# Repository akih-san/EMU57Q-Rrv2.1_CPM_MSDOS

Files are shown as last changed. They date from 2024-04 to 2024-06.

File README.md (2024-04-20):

# EMU57Q-8088/V20<br>
<br>
PIC18F57Q43を使った8088/用のSBCを作成し、CPM-86とMD-DOS2.11を移植し公開しています。<br>
SBCをRev2.1にバージョンアップしました。<br>
8088/V20が4.9MHz、または8MHzで動作します。<br>

EMU57Q-8088/V20 Rev2.1ボード
P 1

Rev2.1では、新たにI2Cをサポートしています。<br>

SBCとI2Cモジュール
P 2

また、新規ファームウェアでは、起動時ＯＳを選択出来るようにしました。<br>
ファイルは、CPM-86用のディレクトリファイルと、MS-DOS用のディレクトリ<br>
ファイルが用意されています。<br>
両方のディレクトリファイルをSDカードにコピーすると、どちらのOSを<br>
起動時するのかをパワーオン／リセット時に聞いてきます。<br>
単一のディレクトリファイルをコピーした場合には、コピーしたOSが起動します。<br>
<br>

CP/M-86起動画面
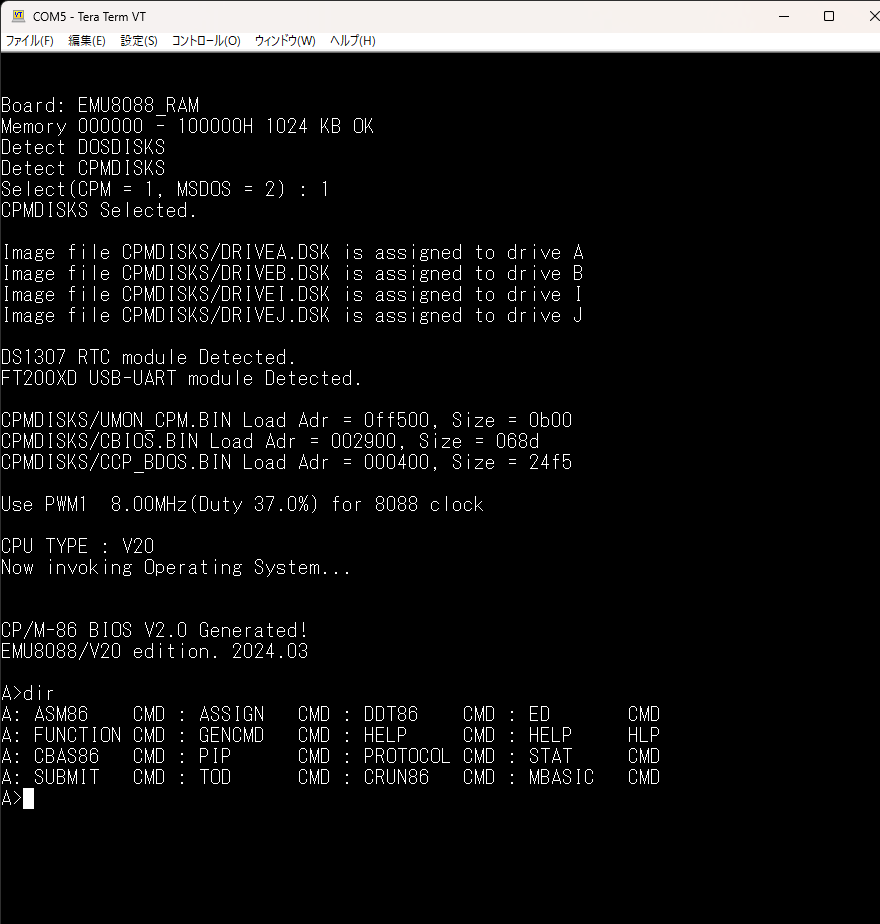
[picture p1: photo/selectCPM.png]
P 3


MS-DOS起動画面
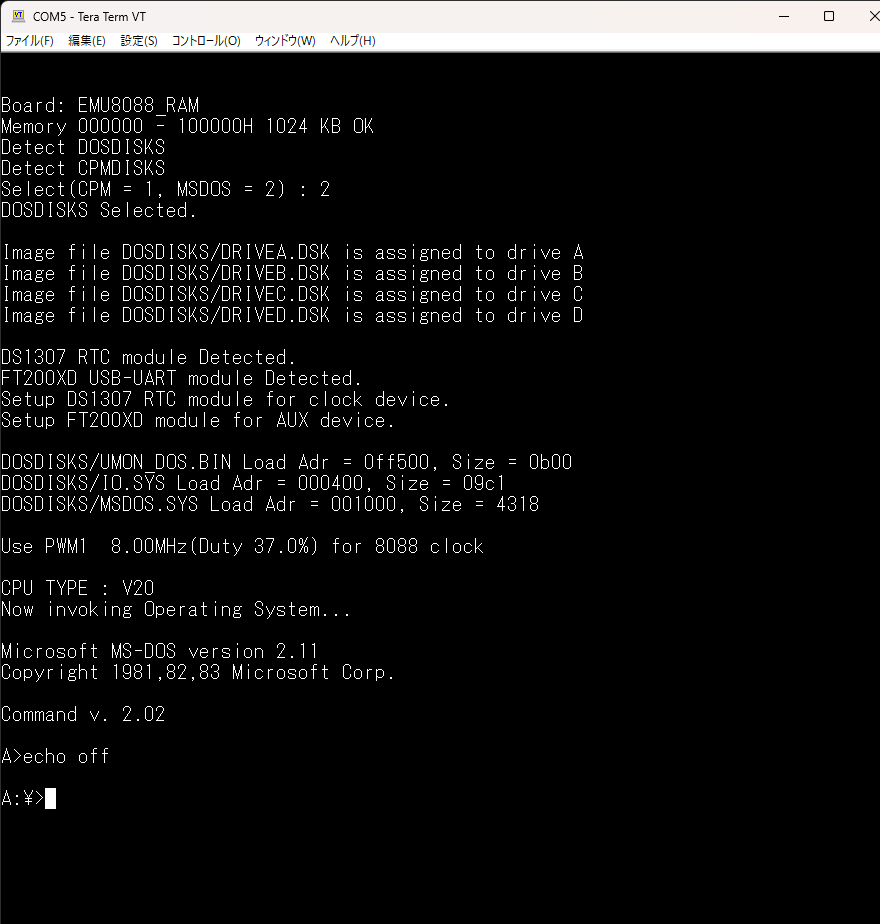
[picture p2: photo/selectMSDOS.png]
P 4


# I2Cのサポート<br>
MS-DOSのクロックデバイスをサポートするためには、リアルタイムクロック<br>
（RTC）が必要です。<br>
PIC18F57Q43にはRTC機能はありません。<br>
（タイマーを使って疑似的に1秒を作り出すことはできます。）<br>
商業用にI2C機能を使ったRTCモジュールが販売されています。<br>
PIC18F57Q43にはI2C機能があるので、これを使えばRTC機能を持たせることが可能となります。<br>
<br>
そういった理由から、I2Cをサポートすることにしました。<br>
また、I2Cを使えば、商業用に販売されている色々なデバイスを動かす<br>
ことが出来ます。<br>
（当然対応するプログラムを作成する必要がありますが・・・）<br>
RTCモジュールとしてサポートしているのは、DS1307を使用したモジュール<br>
となります。また、I2C経由でUSB-UARTに接続するモジュール（FT200-XD)の<br>
サポートも実装してあります。<br>
<br>
I2Cが使えるのは、MS-DOSのみとなっています。CPM-86では扱っていません。<br>
<br>
I2Cのサポートについては、@etoolsLab369さんのページが非常に参考になりました。<br>
感謝いたします。<br>
<br>
（18F27Q43 2台を使ってHost-Client通信）<br>
https://qiita.com/etoolsLab369/items/65befd8fe1cccd3afc33<br>
<br>
<br>
＜DS1307を使ったRTCモジュール＞
P 5
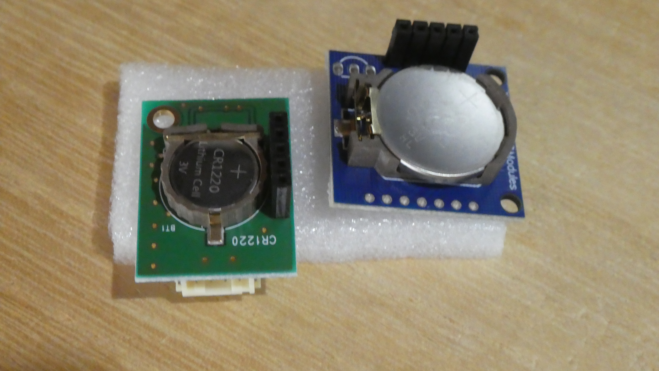
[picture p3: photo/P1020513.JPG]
P 6


AE-DS1307：　秋月電子通商で入手できます。<br>
https://akizukidenshi.com/catalog/g/g115488/<br>
<br>
Tiny RTC modules：　amazon、その他有名webストアで入手できます。<br>
説明書も何もありませんが、amazonに図面入りのレビューがありました。<br>
<br>
<br>
＜FT200XDを使ったUSB-UART接続モジュール＞
P 7

MFT200XD：　マルツのwebストアで入手できます。amazonからでも入手できます。<br>
https://www.marutsu.co.jp/pc/i/243038/<br>
<br>
CJMCU-200：　amazon、その他有名webストアで入手できます。<br>
説明書も何もありませんでしたが、問題なく使えました。<br>
<br>
<br>
# ファームウェア
@hanyazouさんが作成したZ80で動作しているCP/M-80のFWをベースに、<br>
EMU8088_57Q用のFWとして動作するように修正を加えました。<br>
今回は、CPM-86とMS-DOSを、SDカード上にバイナリファイルとして扱っています。<br>
<br>
(CPM-86)<br>
--CPMDISKSディレクトリ<br>
　　CBIOS.BIN　　　　BIOSバイナリファイル<br>
　　CCP_BDOS.BIN　　　CCP, BDOSバイナリファイル<br>
　　UMON_CPM.BIN　　　UNIMONのバイナリファイル<br>
　　DRIVEA.DSK　　　　Aドライブのディスクイメージ<br>
　　DRIVEB.DSK　　　　Bドライブのディスクイメージ<br>
　　DRIVEI.DSK　　　　Iドライブのディスクイメージ<br>
　　DRIVEJ.DSK　　　　Jドライブのディスクイメージ<br>
<br>
(MS-DOS)<br>
--DOSDISKSディレクトリ<br>
　　IO.SYS　　　　　　IOデバイスドライバのバイナリファイル<br>
　　MSDOS.SYS　　　　MS-DOS本体のバイナリファイル<br>
　　UMON_DOS.BIN　　　UNIMONのバイナリファイル<br>
　　DRIVEA.DSK　　　　Aドライブのディスクイメージ<br>
　　DRIVEB.DSK　　　　Bドライブのディスクイメージ<br>
　　DRIVEC.DSK　　　　Cドライブのディスクイメージ<br>
　　DRIVED.DSK　　　　Dドライブのディスクイメージ<br>
<br>
MS-DOS、CPM-86については、以下を参照してください。<br>
<br>
https://github.com/akih-san/EMU8088_57Q_V2_CPM86<br>
https://github.com/akih-san/EMU8088_MSDOS211<br>
<br>
<br>
＜＠hanyazouさんのソース＞<br>
https://github.com/hanyazou/SuperMEZ80/tree/mez80ram-cpm<br>
<br>
＜@electrelicさんのユニバーサルモニタ(UNIMON)＞<br>
https://electrelic.com/electrelic/node/1317<br>
<br>
<br>
# 参考
・EMUZ80<br>
EUMZ80はZ80CPUとPIC18F47Q43のDIP40ピンIC2つで構成されるシンプルな<br>
コンピュータです。<br>
<br>
＜電脳伝説 - EMUZ80が完成＞  <br>
https://vintagechips.wordpress.com/2022/03/05/emuz80_reference  <br>
＜EMUZ80専用プリント基板 - オレンジピコショップ＞  <br>
https://store.shopping.yahoo.co.jp/orangepicoshop/pico-a-051.html<br>
<br>
・SuperMEZ80<br>
SuperMEZ80は、EMUZ80にSRAMを追加し、Z80をノーウェイトで動かすことができるメザニンボードです<br>
<br>
SuperMEZ80<br>
https://github.com/satoshiokue/SuperMEZ80<br>
<br>

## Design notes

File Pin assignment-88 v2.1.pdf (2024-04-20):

8088_RAM

EMUZ80-8088 PIC18F57Q43 | Bit
7 | 6 | 5 | 4 | 3 | 2 | 1 | 0
RA | RXD (UART3) | (UART3) TXD | HOLDA | /A19 (not A19) | A19 | A18 | A17 | A16
U3（74LS373の出力）
RB | AD7 - AD0（DATA BUSとして使用）
（DAA　Bと共用）→ | MISO (SPI1) | SPI_CK (SPI1) | MOSI (SPI1)
RC | CLK （PWM1S1P1_OUT) | NMI / GPIO （I2C設定用） | ALE | SDA(I2C1) / RXD(UART1) | SCL(I2C1) / TXD(UART1) | /RD | /WR | IO/M#
RD | A7 - A0 U2（74LS373）の出力
RE | | | | | | SPI_SS (SPI1) | HOLD | RESET
RF | A15 - A8

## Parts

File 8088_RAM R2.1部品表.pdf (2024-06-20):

8088_RAM R2.1部品表
No. | 部品番号 | 数 | 値、品番 | 名称
1 | C1 | 1 | 47μF 10V以上 | 電解コンデンサー
2 | C2, C3, C4, C5, C6, C7, C8, C9 | 8 | 0.1μF | 積層セラミックコンデンサー
3 | D1, D3, D4 | 3 | ３ｍｍLED | 発光ダイオード
4 | D2 | 1 | 1N4148 | 小信号ダイオード
5 | J1, J2, J3, J4 | 4 | 02x06 | PIC18F47Q43用のソケット（または、ピンヘッダ）
6 | J5 | 1 | MJ-179PH | 2.1mm標準DCジャック(4A) 基板取付用
7 | J6 | 1 | 1x06 | PICプログラム用、2.54mmピッチピンヘッダ
8 | J7 | 1 | 1x06 | μSDカード（SPI)用、2.54mmピッチピンヘッダ
9 | J8 | 1 | 1x06 | UART用、2.54mmピッチピンヘッダ
10 | J9 | 1 | 02x24 | 拡張用2.54mmピッチピンヘッダ
11 | J10 | 1 | 1x03 | TEST信号LOW、HIGH切替用2.54mmピッチピンヘッダ
12 | J11 | 1 | 1x05 | I2C接続用2.54mmピッチピンヘッダ
13 | J12 | 1 | 1x05 | I2C接続用2.54mmピッチピンヘッダ
14 | JP1 | 1 | Jumper(Open) | USB電源接続用ジャンパー2.54mm、２パッド
15 | JP2 | 2 | RSCL | I2Cプルアップ抵抗用ジャンパー2.54mm、２パッド
16 | JP3 | 1 | RSDA | I2Cプルアップ抵抗用ジャンパー2.54mm、２パッド
17 | JP4 | 2 | I2CIO | I2CIOオプションピン接続用ジャンパー2.54mm、２パッド
18 | R1 | 1 | 2.2KΩ 1/4W | カーボン抵抗(炭素皮膜抵抗)
19 | R2, R3, R4, R6, R8, R9 | 6 | 10KΩ 1/4W | カーボン抵抗(炭素皮膜抵抗)
20 | R5, R7 | 2 | 1.5KΩ 1/4W | カーボン抵抗(炭素皮膜抵抗)
21 | RN1 | 1 | 6素子 10kΩ | 集合抵抗 6素子
22 | RN2, RN3, RN4 | 3 | 8素子 10kΩ | 集合抵抗 8素子
23 | S1 | 1 | SS-12D00G3 | スライドスイッチ 1回路2接点 基板用
24 | SW1 | 1 | DTS-63-N-V | タクトスイッチ（リセット用）
25 | U1 | 1 | CPU 8088 / V20 | 8088または、V20（DIP40)
26 | U2, U3 | 2 | 74LS373 | 8ビットラッチ（DIP20)
27 | U4, U5 | 2 | AS6C4008-55PCN | 512kw×8bit SRAM（DIP32)
28 | U6 | 1 | 74HC125 | スリーステートバッファ（4回路、DIP14）
29 | PIC18F57Q43 | 1 | AE-QFP48PR5-DIP | PIC18F57Q43実装基板

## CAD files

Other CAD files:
i86src/msdos/emu88io.OBJ
i86src/msdos/SYSIMES.OBJ
i86src/msdos/SYSINIT.OBJ

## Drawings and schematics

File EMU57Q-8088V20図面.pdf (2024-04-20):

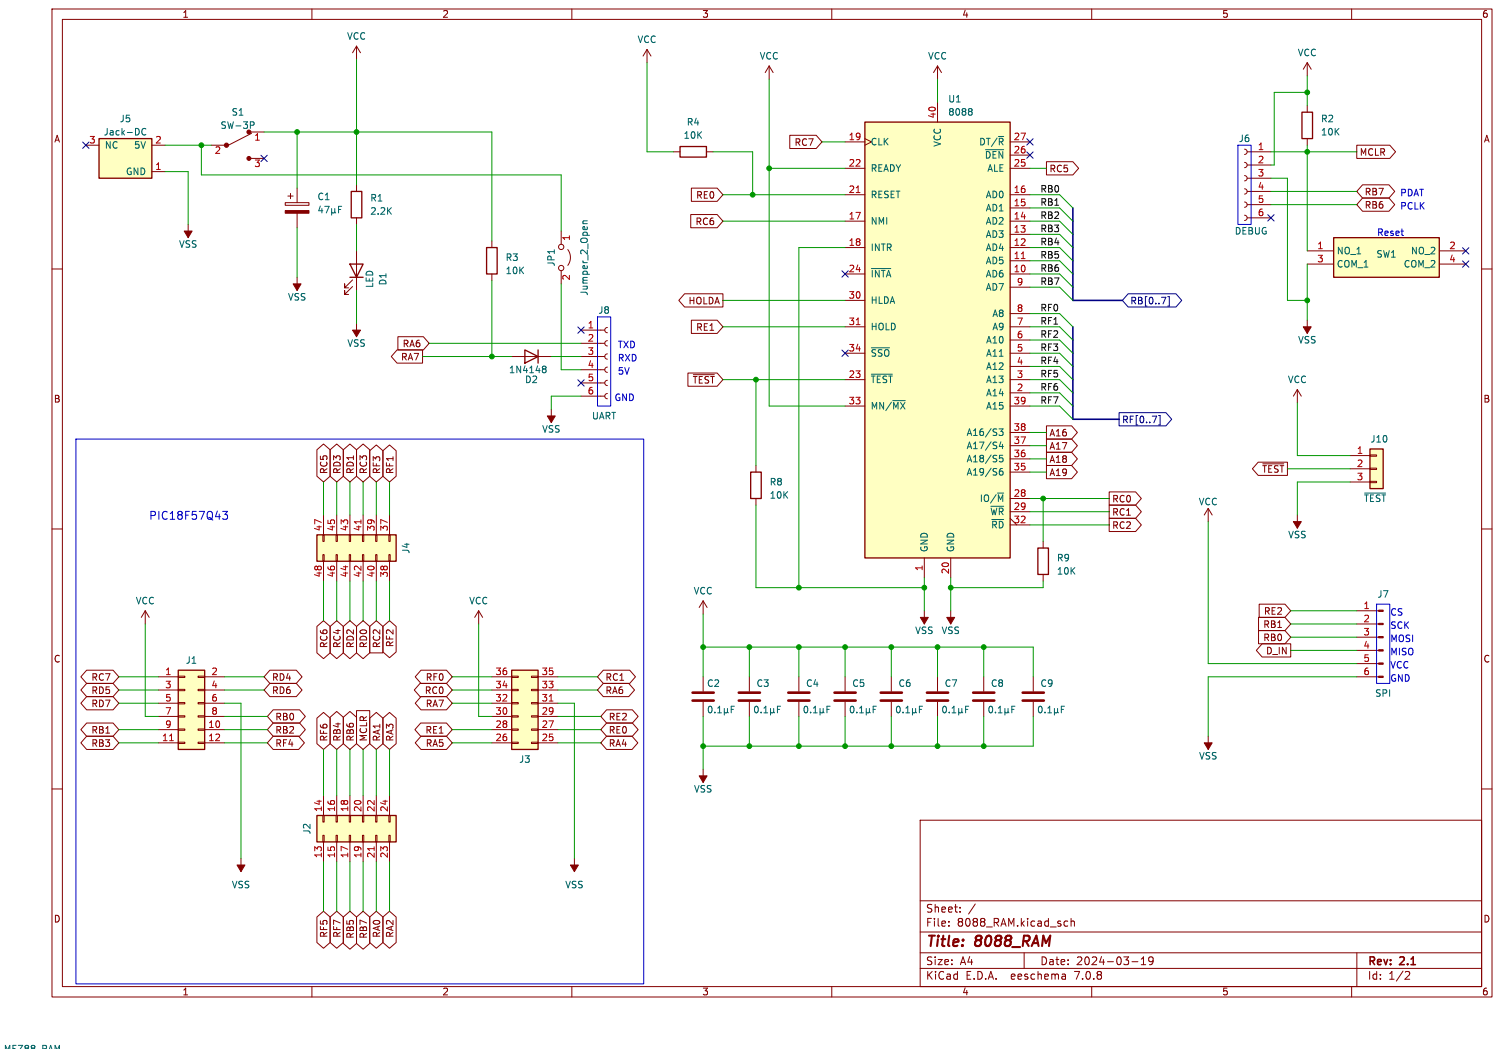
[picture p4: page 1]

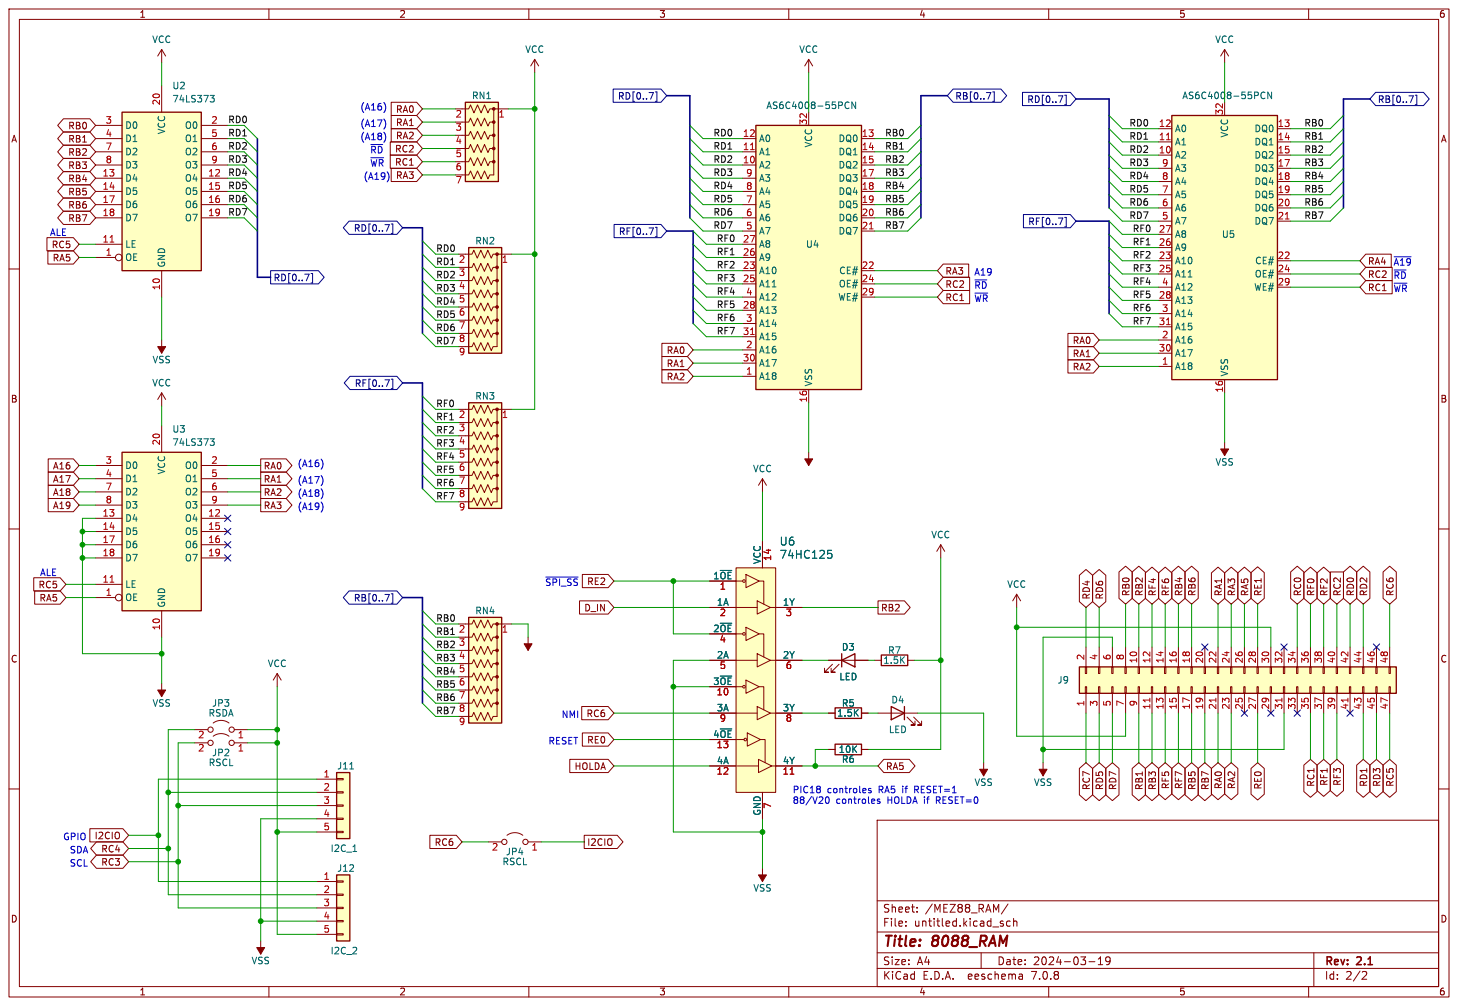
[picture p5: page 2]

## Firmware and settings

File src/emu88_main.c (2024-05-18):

/*
 * CP/M-86 and MS-DOS for EMU57Q-8088/V20_RAM
 * This firmware is only for PICF57Q43.
 * This firmware can run CPM-86 or MS-DOS on CPU i8088/V20.
 *
 * Based on main.c by Tetsuya Suzuki 
 * and emuz80_z80ram.c by Satoshi Okue
 * PIC18F47Q43/PIC18F47Q83/PIC18F47Q84 ROM image uploader
 * and UART emulation firmware.
 * This single source file contains all code.
 *
 * Base source code of this firmware is maked by
 * @hanyazou (https://twitter.com/hanyazou) *
 *
 *  Target: EMU57Q-8088/V20_RAM 1MB Rev2.1
 *  Written by Akihito Honda (Aki.h @akih_san)
 *  https://twitter.com/akih_san
 *  https://github.com/akih-san
 *
 *  Date. 2024.4.20
 */

#define INCLUDE_PIC_PRAGMA
#include "../src/emu88.h"
#include <stdio.h>
#include <stdlib.h>
#include <string.h>
#include "../drivers/utils.h"

static FATFS fs;
static DIR fsdir;
static FILINFO fileinfo;
static FIL files[NUM_FILES];
static FIL rom_fl;

uint8_t tmp_buf[2][TMP_BUF_SIZE];
#define BUF_SIZE TMP_BUF_SIZE * 2

static int os_flg;
debug_t debug = {
    0,  // disk
    0,  // disk_read
    0,  // disk_write
    0,  // disk_verbose
    0,  // disk_mask
};

static char *cpmdir	= "CPMDISKS";
static char *msdosdir	= "DOSDISKS";

static int disk_init(void);
static int chk_os(void);
static void setup_cpm(void);
static void setup_msdos(void);
static int open_dskimg(void);
static int load_program(const TCHAR *buf, uint32_t load_adr, uint16_t *load_size);

static char *board_name = "EMU8088_RAM";

// main routine
void main(void)
{
	sys_init();
	devio_init();

	printf("Board: %s\n\r", board_name);

    mem_init();
    if (disk_init() < 0) while (1);

	// Check OS
	os_flg = chk_os();		//1: CPM,  2:MSDOS, -1:error
	printf("\n\r");

	// open disk drive
	if ( open_dskimg() < 0 ) {
        printf("No boot disk.\n\r");
		while(1);
	}
	printf("\n\r");

	switch( os_flg ) {
		case CPM:
			setup_cpm();
			break;
		case MSDOS:
			setup_msdos();
			break;
		default:
			printf("No OS directory.\n\r");
			while (1);
	}

	printf("\n\r");

	//
    // Start i8088
    //
    printf("Use PWM1  %.2fMHz(Duty %.1f%%) for 8088 clock\n\r", 
    			1/((PWM1PR+1)*P64)*1000, (double)(PWM1S1P1*100/(PWM1PR+1)));
    printf("\n\r");
	
    start_i88();
	board_event_loop();
}

static void setup_msdos(void) {

	const TCHAR	buf[30];
	int flg;
	uint16_t size, sec_size, ld_adr;

	// set dos operation 
	bus_master_operation = dos_bus_master_operation;

	dosio_init();
	setup_clk_aux();
	printf("\n\r");

	sec_size = dos_sec_size();
	sprintf((char *)buf, "%s/UMON_DOS.BIN", fileinfo.fname);
	flg = load_program(buf, UNIMON_OFF, &size);
	if (!flg) {
		sprintf((char *)buf, "%s/IO.SYS", fileinfo.fname);
		flg = load_program(buf, IOSYS_OFF, &size);
		if (!flg) {
			ld_adr = (((size+sec_size) / sec_size)+1)*sec_size+IOSYS_OFF;
			sprintf((char *)buf, "%s/MSDOS.SYS", fileinfo.fname);
			flg = load_program(buf, (uint32_t)ld_adr, &size);
		}
	}
	if ( flg ) {
		printf("Program File Load Error.\r\n");
		while(1);
	}
}


static void setup_cpm(void) {
	
	const TCHAR	buf[30];
	int flg;
	uint16_t size;

	// set cpm operation
	bus_master_operation = cpm_bus_master_operation;

	cpmio_init();
	setup_I2C();
	if (!chk_i2cdev()) setup_uart1();
	printf("\n\r");

	sprintf((char *)buf, "%s/UMON_CPM.BIN", fileinfo.fname);
	flg = load_program(buf, UNIMON_OFF, &size);
	if (!flg) {
		sprintf((char *)buf, "%s/CBIOS.BIN", fileinfo.fname);
		flg = load_program(buf, BIOS_OFF, &size);
		if (!flg) {
			sprintf((char *)buf, "%s/CCP_BDOS.BIN", fileinfo.fname);
			flg = load_program(buf, CCP_OFF, &size);
		}
	}
	if ( flg ) {
		printf("Program File Load Error.\r\n");
		while(1);
	}
}

//
// load program from SD card
//
static int load_program(const TCHAR *buf, uint32_t load_adr, uint16_t *load_size) {
	
	FRESULT		fr;
	void		*rdbuf;
	UINT		btr, br;
	uint16_t	cnt;
	uint32_t	adr;

	rdbuf = (void *)&tmp_buf[0][0];		// program load work area(512byte)
	
	fr = f_open(&rom_fl, buf, FA_READ);
	if ( fr != FR_OK ) return((int)fr);

	adr = load_adr;
	cnt = *load_size = (uint16_t)f_size(&rom_fl);	// get file size
	btr = BUF_SIZE;									// default 512byte
	while( cnt ) {
		fr = f_read(&rom_fl, rdbuf, btr, &br);
		if (fr == FR_OK) {
			write_sram(adr, (uint8_t *)rdbuf, (unsigned int)br);
			adr += (uint32_t)br;
			cnt -= (uint16_t)br;
			if (btr > (UINT)cnt) btr = (UINT)cnt;
		}
		else break;
	}
	if (fr == FR_OK) {
		printf("%s Load Adr = %06lx, Size = %04x\r\n", (char *)buf, load_adr, *load_size);
	}
	f_close(&rom_fl);
	return((int)fr);
}

//
// mount SD card
//
static int disk_init(void)
{
    if (f_mount(&fs, "0://", 1) != FR_OK) {
        printf("Failed to mount SD Card.\n\r");
        return -2;
    }

    return 0;
}

//
// check OS and select OS
//
static int chk_os(void)
{
    int selection;
    uint8_t c;

    //
    // Select disk image folder
    //
    if (f_opendir(&fsdir, "/")  != FR_OK) {
        printf("Failed to open SD Card..\n\r");
        return -1;
    }

	selection = 0;
	f_rewinddir(&fsdir);
	while (f_readdir(&fsdir, &fileinfo) == FR_OK && fileinfo.fname[0] != 0) {
		if (strcmp(fileinfo.fname, cpmdir) == 0) {
			selection |= CPM;
			printf("Detect %s\n\r", fileinfo.fname);
		}
		if (strcmp(fileinfo.fname, msdosdir) == 0) {
			selection |= MSDOS;
			printf("Detect %s\n\r", fileinfo.fname);
		}
	}
	switch( selection) {
		case 0:			// directory not found
			return(-1);

		case CPM:
		case MSDOS:
			break;

		default:
			// remain CPM+MSDOS:
           	selection = CPM;
    	    printf("Select(CPM = 1, MSDOS = 2) : ");
    	    while (1) {
            	c = (uint8_t)getch();  // Wait for input char
    	    	if ( c == '1' || c == '2' ) {
    	    		putch((char)c);
	            	selection = c - '0';
    	    	}
   	    		if ( c == 0x0d || c == 0x0a ) break;
    	    }
   	    	printf("\n\r");
	}
	if ( selection == CPM) strcpy(fileinfo.fname, cpmdir);
	else strcpy(fileinfo.fname, msdosdir);
	printf("%s Selected.\n\r", fileinfo.fname);
	f_closedir(&fsdir);
	
	return(selection);
}

	
//
// Open disk images
//
static int open_dskimg(void) {
	
	int num_files;
    uint16_t drv;
	
	for (drv = num_files = 0; drv < NUM_DRIVES && num_files < NUM_FILES; drv++) {
        char drive_letter = (char)('A' + drv);
        char * const buf = (char *)tmp_buf[0];
        sprintf(buf, "%s/DRIVE%c.DSK", fileinfo.fname, drive_letter);
        if (f_open(&files[num_files], buf, FA_READ|FA_WRITE) == FR_OK) {

        	printf("Image file %s/DRIVE%c.DSK is assigned to drive %c\n\r",
                   fileinfo.fname, drive_letter, drive_letter);
        	if (os_flg == CPM) {
	        	cpm_drives[drv].filep = &files[num_files];
				if (cpm_drives[0].filep == NULL) return -4;
        	}
        	else {
        		dos_drives[drv].filep = &files[num_files];
				if (dos_drives[0].filep == NULL) return -4;
        	}
        	num_files++;
        }
    }
    return 0;
}

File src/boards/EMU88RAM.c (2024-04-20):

/*
 *  This source is for PIC18F57Q43 UART, I2C, SPI and TIMER0
 *
 * Base source code is maked by @hanyazou
 *  https://twitter.com/hanyazou
 *
 * Redesigned by Akihito Honda(Aki.h @akih_san)
 *  https://twitter.com/akih_san
 *  https://github.com/akih-san
 *
 *  Target: PIC18F57QXX
 *  Date. 2024.4.20
*/

#define BOARD_DEPENDENT_SOURCE

#include "../../src/emu88.h"
#include <stdio.h>
#include "../../drivers/SDCard.h"
#include "../../drivers/picregister.h"

#define SPI_PREFIX      SPI_SD
#define SPI_HW_INST     SPI1
#include "../../drivers/SPI.h"

#define I88_DATA        B
#define I88_ADDR_H      F
#define I88_ADDR_L      D

#define I88_A16		A0
#define I88_A17		A1
#define I88_A18		A2
#define I88_A19		A3

#define I88_IOM		C0
#define I88_ALE		C5

#define I88_RESET	E0
#define I88_HOLD	E1		// BUS request
#define I88_HOLDA	A5

// /WR
#define I88_WR		C1
// /RD
#define I88_RD		C2

// CLK
#define I88_CLK		C7
#define I88_NMI		C6

#define SPI_SS		E2
#define SPI_SD_POCI	B2

#define SPI_SD_PICO     B0
#define SPI_SD_CLK      B1
#define SPI_SD_SS       SPI_SS

#define URT1_RXD		C4
#define URT1_TXD		C3


#define CMD_REQ CLC3OUT

#include "emu88_common.c"

static void reset_ioreq(void);
void (*bus_master_operation)(void);

void sys_init()
{
    emu88_common_sys_init();

	// NMI definition
	WPU(I88_NMI) = 0;     // disable week pull up
	PPS(I88_NMI) = 0;     // set as latch port
	LAT(I88_NMI) = 0;     // NMI=0
	TRIS(I88_NMI) = 0;    // Set as output

	// HOLD output pin
    LAT(I88_HOLD) = 1;
    TRIS(I88_HOLD) = 0;          // Set as output
	
	// IO/#M
	WPU(I88_IOM) = 1;     // I88_IOM Week pull up
	LAT(I88_IOM) = 0;     // memory /CE active
	TRIS(I88_IOM) = 0;    // Set as onput

	// ALE
	WPU(I88_ALE) = 0;     // disable week pull up
    TRIS(I88_ALE) = 1;    // Set as input

	// /WR output pin
	WPU(I88_WR) = 1;		// /WR Week pull up
    LAT(I88_WR) = 1;		// disactive
    TRIS(I88_WR) = 0;		// Set as output
    PPS(I88_WR) = 0x00;	//reset:output PPS is LATCH

	// /RD output pin
	WPU(I88_RD) = 1;		// /WR Week pull up
    LAT(I88_RD) = 1;		// disactive
    TRIS(I88_RD) = 0;		// Set as output
    PPS(I88_RD) = 0x00;	//reset:output PPS is LATCH

	// SPI_SS
	WPU(SPI_SS) = 1;     // SPI_SS Week pull up
	LAT(SPI_SS) = 1;     // set SPI disable
	TRIS(SPI_SS) = 0;    // Set as onput

	LAT(I88_CLK) = 1;	// 8088_CLK = 1
    TRIS(I88_CLK) = 0;	// set as output pin
	
	//RA4 : setup /A19
	WPUA4 = 1;			// Week pull up
	TRISA4 = 0;			// Set as output
	RA4PPS = 0x01;		// CLC1OUT ( not A19 ) -> RA4

// Setup CLC
//
	//========== CLC pin assign ===========
    CLCIN4PPS = 0x15;			// assign RC5(ALE)
    CLCIN5PPS = 0x10;			// assign RC0(IO/M#)
	CLCIN0PPS = 0x03;			// assign RA3(A19)

	//========== CLC1 : make not A19  ==========
	CLCSELECT = 0;		// CLC1 select

	CLCnSEL0 = 0;		// CLCIN0PPS : RA3(A19)
	CLCnSEL1 = 127;		// NC
	CLCnSEL2 = 127;		// NC
	CLCnSEL3 = 127;		// NC

    CLCnGLS0 = 0x01;	// invert A19 -> log1
    CLCnGLS1 = 0x00;	// not gated
    CLCnGLS2 = 0x00;	// not gated
    CLCnGLS3 = 0x00;	// not gated

    CLCnPOL = 0x0e;		// POL=0, (G4POL,G3POL,G2POL)=1, G1POL=1
    CLCnCON = 0x82;		// 4-Input AND , no interrupt occurs

	
	//========== CLC3 : IOREQ ==========
	// reset DFF with software(reset_ioreq();)

	CLCSELECT = 2;		// CLC3 select

	CLCnSEL0 = 4;		// CLCIN4PPS : RC5(ALE)
    CLCnSEL1 = 5;		// CLCIN5PPS : RC0(IO/M#)
	CLCnSEL2 = 0x35;	// CLC3OUT
	CLCnSEL3 = 127;		// NC

    CLCnGLS0 = 0x02;	// ALE -> (log1) DFF(CK)
	CLCnGLS1 = 0x08;	// IO/#M - > (log2) OR gate
    CLCnGLS2 = 0x00;	// not gated
    CLCnGLS3 = 0x20;	// CLC3OUT -> (log4) OR gate

    CLCnPOL = 0x00;		// POL=0
    CLCnCON = 0x85;		// 2-Input DFF with R , no interrupt occurs

	// reset CLC3
	reset_ioreq();

	// SPI data and clock pins slew at maximum rate

	SLRCON(SPI_SD_PICO) = 0;
	SLRCON(SPI_SD_CLK) = 0;
	SLRCON(SPI_SD_POCI) = 0;

/*********** CLOCK TIMING ************************
 I88_CLK TIMING REQUIREMENTS(MUST)
 CLK Low Time  : minimum 118ns
 CLK High Time : minimum 69ns
*************************************************/

/**************** PWM1 ********************
// 8088 TIMING REQUIREMENTS(MUST)
// CLK Low Time  : minimum 118ns
// CLK High Time : minimum 69ns
// CLK duty 33%

// P64 = 1/64MHz = 15.625ns
// P5  = 1/5MHz  = 200ns = P64 * 12.8
// P8  = 1/8MHz  = 125nz = P64 * 8
//
// --- 4.92MHz ---
// Set PWM Left Aligned mode
// PR = 12
// P1 = 5 : P64*5 = 78.125ns
// P2 = 8 : P64*8 = 125ns
// MODE = 0
//     high period time: 78.125ns
//     low period time: 125ns
//     78.125 + 125ns = 203.125ns f = 4923076.9230769230769230769230769 Hz
//     duty = 38.4%
// --- 8MHz ---
// Set PWM Left Aligned mode
// PR = 7
// P1 = 3 : P64*3 = 46.875ns
// P2 = 5 : P64*5 = 78.125ns
// MODE = 0
//     high period time: 46.875ns
//     low period time: 78.125ns
//     46.875ns + 78.125 = 125ns f = 8 Hz
//     duty = 37.5%
******************************************/

	PWM1CLK = 0x02;		// Fsoc
	PWM1GIE = 0x00;		// interrupt disable
#ifdef CLK8M
//8MHz
	PWM1PR = 0x0007;	// 8 periods ( 0 - 7 )
	PWM1S1P1 = 0x0003;	// P1 = 3
	PWM1S1P2 = 0x0005;	// P2 = 5
#else
//5MHz
	PWM1PR = 0x000C;	// 13 periods ( 0 - 12 )
	PWM1S1P1 = 0x0005;	// P1 = 5
	PWM1S1P2 = 0x0008;	// P2 = 8
#endif
	PWM1S1CFG = 0x00;	// (POL1, POL2)= 0, PPEN = 0 MODE = 0 (Left Aligned mode)
	PWM1CON = 0x84;		// EN=1, LD=1
	RC7PPS = 0x18;		// PWM1S1P1_OUT

    emu88_common_wait_for_programmer();

    //
    // Initialize SD Card
    //
    static int retry;
    for (retry = 0; 1; retry++) {
        if (20 <= retry) {
            printf("No SD Card?\n\r");
            while(1);
        }
//        if (SDCard_init(SPI_CLOCK_100KHZ, SPI_CLOCK_2MHZ, /* timeout */ 100) == SDCARD_SUCCESS)
        if (SDCard_init(SPI_CLOCK_100KHZ, SPI_CLOCK_4MHZ, /* timeout */ 100) == SDCARD_SUCCESS)
//        if (SDCard_init(SPI_CLOCK_100KHZ, SPI_CLOCK_8MHZ, /* timeout */ 100) == SDCARD_SUCCESS)
            break;
        __delay_ms(200);
    }

	GIE = 1;             // Global interrupt enable
}

// ************ timer0 setup ******************
void setup_tomer0(void) {

	T0CON0 = 0x90;	// timer enable, 16bit counter mode , 1:1 Postscaler
	T0CON1 = 0x80;	// sorce clk:LFINTOSC, 1:1 Prescaler
	LFOEN = 1;		// LFINTOSC is explicitly enabled

	TMR0L = TIMER0_INITCL;
	TMR0H = TIMER0_INITCH;		//	timer counter set to 0x86e8
								//  LFINTOSC = 31Khz!!
	timer0_init();

	TMR0IF =0; // Clear timer0 interrupt flag
	TMR0IE = 1;	// Enable timer0 interrupt
}
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
